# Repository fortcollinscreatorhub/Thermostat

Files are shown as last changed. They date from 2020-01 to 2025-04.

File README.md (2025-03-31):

# What is this repository?

This repository contains files for the custom thermostats used at the Fort
Collins Creator Hub.

# How to clone this repository

This project uses git submodules, unfortunately. To clone the repository, run:

```shell
git clone --recurse-submodules https://github.com/fortcollinscreatorhub/Thermostat
```

If you wish to push back to the github repo, you probably want to clone with
`ssh`, or edit `.git/config` to use ssh URLs after cloning, e.g.:

```shell
git clone --recurse-submodules git@github.com:fortcollinscreatorhub/Thermostat
```

Or after cloning:

```shell
vi .git/config
```

Even if you clone using the ssh URL, you'll still need to edit the remote
definition for each submodule after the initial clone operation.

## Hardware Revisions

v1 was a a breadboard-based design, using some standalone (non-WiFi)
micro-controller; perhaps an AVR or STM32. For this design, we only have the
software and not schematics etc.

v2 uses an ESP32. The PCB design is found in directory [pcb/](pcb/). File
[thermostat.dxf](thermostat.dxf) describes some of the physical design.

## Software Versions

v1 hardware uses the code in directory [code/arduino-v1/](code/arduino-v1/).

v2 hardware can use any of following software stacks:
* A port of the older Arduino code. Found in directory
[code/arduino-esp32/](code/arduino-esp32/).
* WiFi-/MQTT-capable software built using the ESP-IDF framework. Found in
directory [code/esp-idf](code/esp-idf). This version is currently deployed.
* Updated WiFi-/MQTT-capable software built using the ESP-IDF framework, plus
the FCCH "connection manager" component which provides a permanently enabled
password-protected web admin interface. Found in directory
[code/esp-idf-v2](code/esp-idf-v2). This version is not yet deployed.

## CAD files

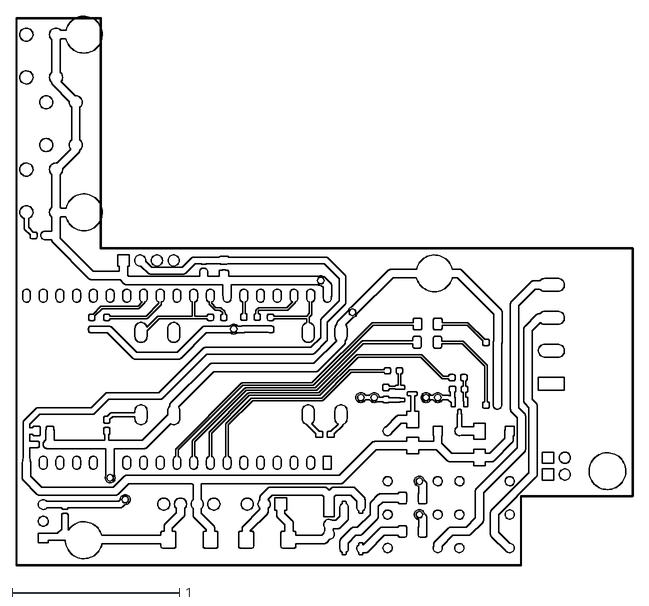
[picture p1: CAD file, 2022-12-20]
pcb/Gerber/Thermostat1-F_Cu.dxf
3.69 x 3.29

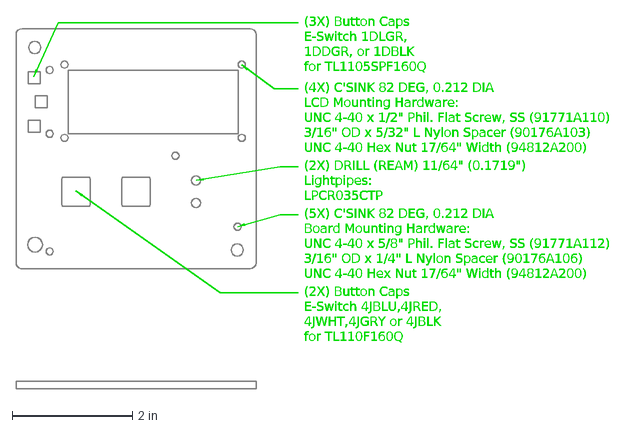
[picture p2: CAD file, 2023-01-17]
thermostat.dxf
(4X) C'SINK 82 DEG, 0.212 DIA LCD Mounting Hardware: UNC 4-40 x 1/2" Phil. Flat Screw, SS (91771A110) 3/16" OD x 5/32" L Nylon Spacer (90176A103) UNC 4-40 Hex N
(3X) Button Caps E-Switch 1DLGR, 1DDGR, or 1DBLK for TL1105SPF160Q
(2X) Button Caps E-Switch 4JBLU,4JRED, 4JWHT,4JGRY or 4JBLK for TL110F160Q
(5X) C'SINK 82 DEG, 0.212 DIA Board Mounting Hardware: UNC 4-40 x 5/8" Phil. Flat Screw, SS (91771A112) 3/16" OD x 1/4" L Nylon Spacer (90176A106) UNC 4-40 Hex 
(2X) DRILL (REAM) 11/64" (0.1719") Lightpipes: LPCR035CTP

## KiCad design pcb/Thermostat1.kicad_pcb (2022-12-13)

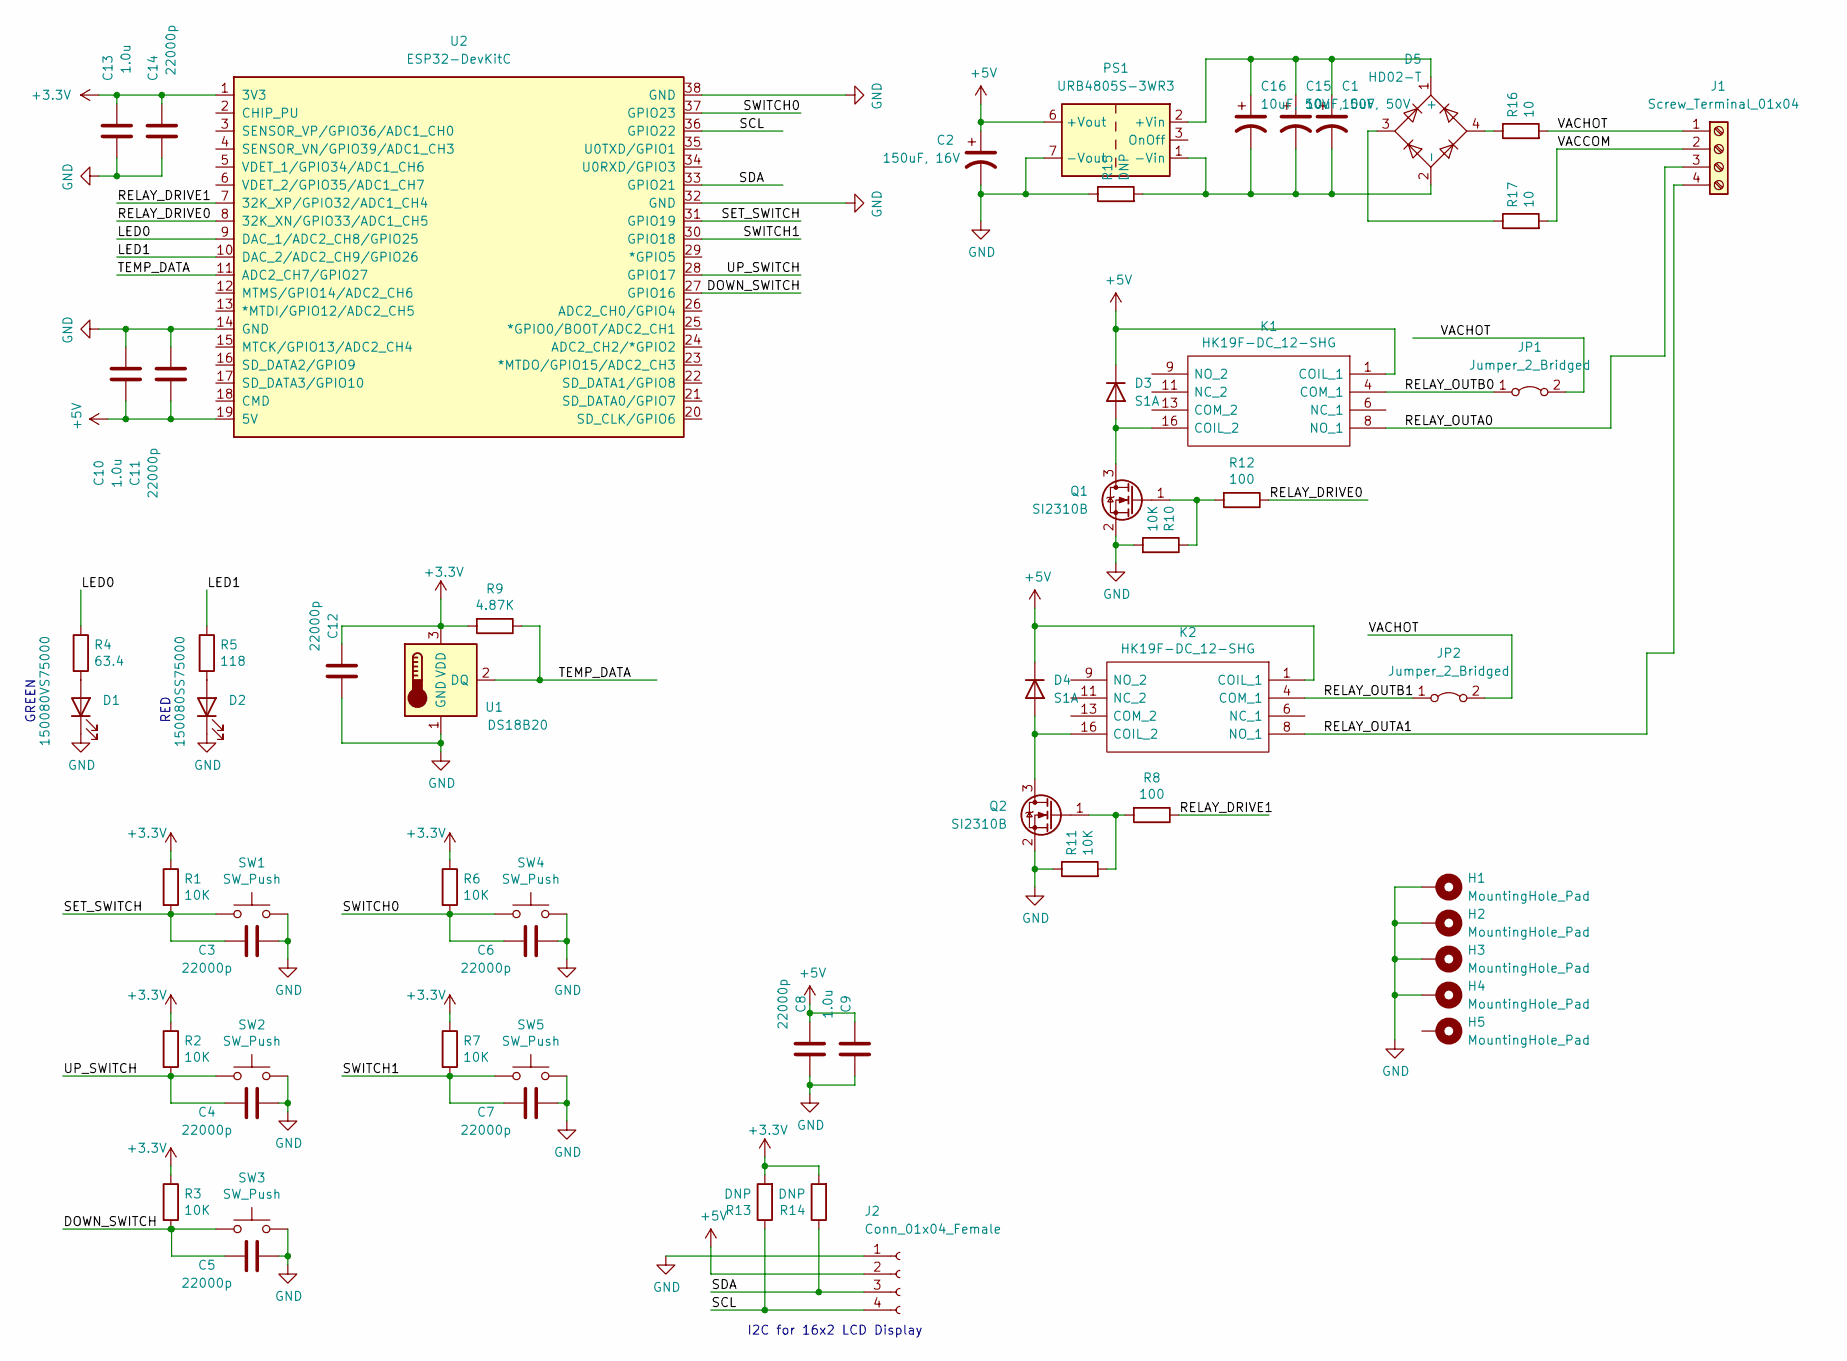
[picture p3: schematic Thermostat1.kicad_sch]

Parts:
C1: 10uF, 50V; CP_EIA-7343-43_Kemet-X_Pad2.25x2.55mm_HandSolder
C2: 150uF, 16V; CP_EIA-7343-43_Kemet-X_Pad2.25x2.55mm_HandSolder
C3, C4, C5, C6, C7, C8, C11, C12, C14: 22000p; C_0603_1608Metric_Pad1.08x0.95mm_HandSolder
C9, C10, C13: 1.0u; C_0805_2012Metric_Pad1.18x1.45mm_HandSolder
C15: 10uF, 50V; CP_Radial_D5.0mm_P2.00mm
C16: 10uF, 50V; CP_Radial_D8.0mm_P5.00mm
D1: 150080VS75000; LED_0603_1608Metric_Pad1.05x0.95mm_HandSolder
D2: 150080SS75000; LED_0603_1608Metric_Pad1.05x0.95mm_HandSolder
D3, D4: S1A; D_SMA
D5: HD02-T; SO-4_4.4x3.9mm_P2.54mm
H1, H2, H3, H4, H5: MountingHole_Pad; MountingHole_3.2mm_M3_DIN965_Pad
J1: Screw_Terminal_01x04; TerminalBlock_Altech_AK300-4_P5.00mm
J2: Conn_01x04_Female; PinHeader_1x04_P2.54mm_Vertical
JP1, JP2: Jumper_2_Bridged; PinHeader_1x02_P2.54mm_Vertical
K1, K2: HK19F-DC_12-SHG; Relay_DPDT_Omron_G5V-2; Manufacturer_Part_Number HK19F-DC 12-SHG
PS1: URB4805S-3WR3; Converter_DCDC_XP_POWER-ITxxxxxS_THT
Q1, Q2: SI2310B; SOT-23
R1, R2, R3, R6, R7, R10, R11: 10K; R_0603_1608Metric_Pad0.98x0.95mm_HandSolder
R4: 63.4; R_1206_3216Metric_Pad1.30x1.75mm_HandSolder
R5: 118; R_1206_3216Metric_Pad1.30x1.75mm_HandSolder
R8, R12: 100; R_0603_1608Metric_Pad0.98x0.95mm_HandSolder
R9: 4.87K; R_0603_1608Metric_Pad0.98x0.95mm_HandSolder
R13, R14: DNP; R_0603_1608Metric_Pad0.98x0.95mm_HandSolder
R15: DNP; R_1206_3216Metric_Pad1.30x1.75mm_HandSolder
R16, R17: 10; R_1206_3216Metric_Pad1.30x1.75mm_HandSolder
SW1, SW2, SW3: SW_Push; SW_PUSH_6mm
SW4, SW5: SW_Push; SW_PUSH-12mm
U1: DS18B20; TO-92_Inline_Wide
U2: ESP32-DevKitC

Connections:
+3.3V: C12.1, C13.1, C14.1, R1.1, R2.1, R3.1, R6.1, R7.1, R9.2, R13.2, R14.2, U1.3 (VDD), U2.1 (3V3)
+5V: C2.1, C8.1, C9.1, C10.2, C11.2, D3.1 (K), D4.1 (K), J2.2, K1.1 (COIL_1), K2.1 (COIL_1), PS1.6 (+Vout), U2.19 (5V)
/DOWN_SWITCH: C5.1, R3.2, SW3.1, U2.27 (GPIO16)
/LED0: R4.1, U2.9 (DAC_1/ADC2_CH8/GPIO25)
/LED1: R5.1, U2.10 (DAC_2/ADC2_CH9/GPIO26)
/RELAY_DRIVE0: R12.1, U2.8 (32K_XN/GPIO33/ADC1_CH5)
/RELAY_DRIVE1: R8.1, U2.7 (32K_XP/GPIO32/ADC1_CH4)
/RELAY_OUTA0: J1.3, K1.8 (NO_1)
/RELAY_OUTA1: J1.4, K2.8 (NO_1)
/RELAY_OUTB0: JP1.1 (A), K1.4 (COM_1)
/RELAY_OUTB1: JP2.1 (A), K2.4 (COM_1)
/SCL: J2.4, R13.1, U2.36 (GPIO22)
/SDA: J2.3, R14.1, U2.33 (GPIO21)
/SET_SWITCH: C3.1, R1.2, SW1.1, U2.31 (GPIO19)
/SWITCH0: C6.1, R6.2, SW4.1, U2.37 (GPIO23)
/SWITCH1: C7.1, R7.2, SW5.1, U2.30 (GPIO18)
/TEMP_DATA: R9.1, U1.2 (DQ), U2.11 (ADC2_CH7/GPIO27)
/UP_SWITCH: C4.1, R2.2, SW2.1, U2.28 (GPIO17)
/VACCOM: J1.2, R17.2
/VACHOT: J1.1, JP1.2 (B), JP2.2 (B), R16.2
GND: C2.2, C3.2, C4.2, C5.2, C6.2, C7.2, C8.2, C9.2, C10.1, C11.1, C12.2, C13.2, C14.2, D1.1 (K), D2.1 (K), H1.1, H2.1, H3.1, H4.1, J2.1, PS1.7 (-Vout), Q1.2 (S), Q2.2 (S), R10.2, R11.1, R15.1, SW1.2, SW2.2, SW3.2, SW4.2, SW5.2, U1.1 (GND), U2.14 (GND), U2.32 (GND), U2.38 (GND)
unnamed: C1.1, C15.1, C16.1, D5.1 (+), PS1.2 (+Vin)
unnamed: C1.2, C15.2, C16.2, D5.2 (-), PS1.1 (-Vin), R15.2
unnamed: D1.2 (A), R4.2
unnamed: D2.2 (A), R5.2
unnamed: D3.2 (A), K1.16 (COIL_2), Q1.3 (D)
unnamed: D4.2 (A), K2.16 (COIL_2), Q2.3 (D)
unnamed: D5.3, R17.1
unnamed: D5.4, R16.1
unnamed: Q1.1 (G), R10.1, R12.2
unnamed: Q2.1 (G), R8.2, R11.2

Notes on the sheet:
I2C for 16x2 LCD Display
RED
GREEN

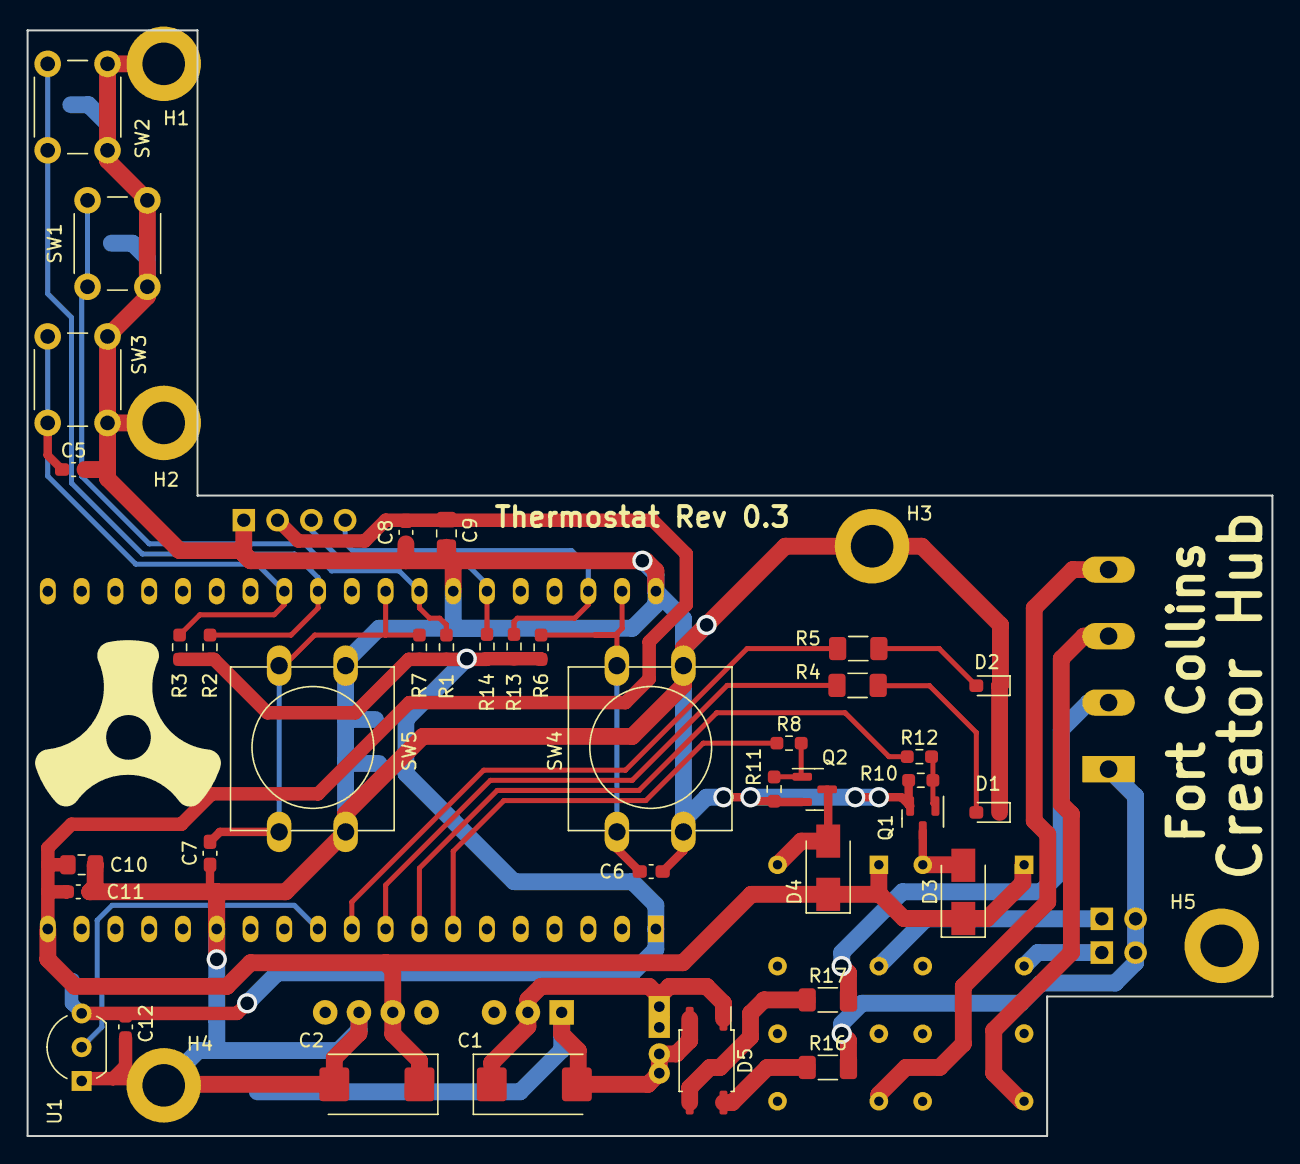
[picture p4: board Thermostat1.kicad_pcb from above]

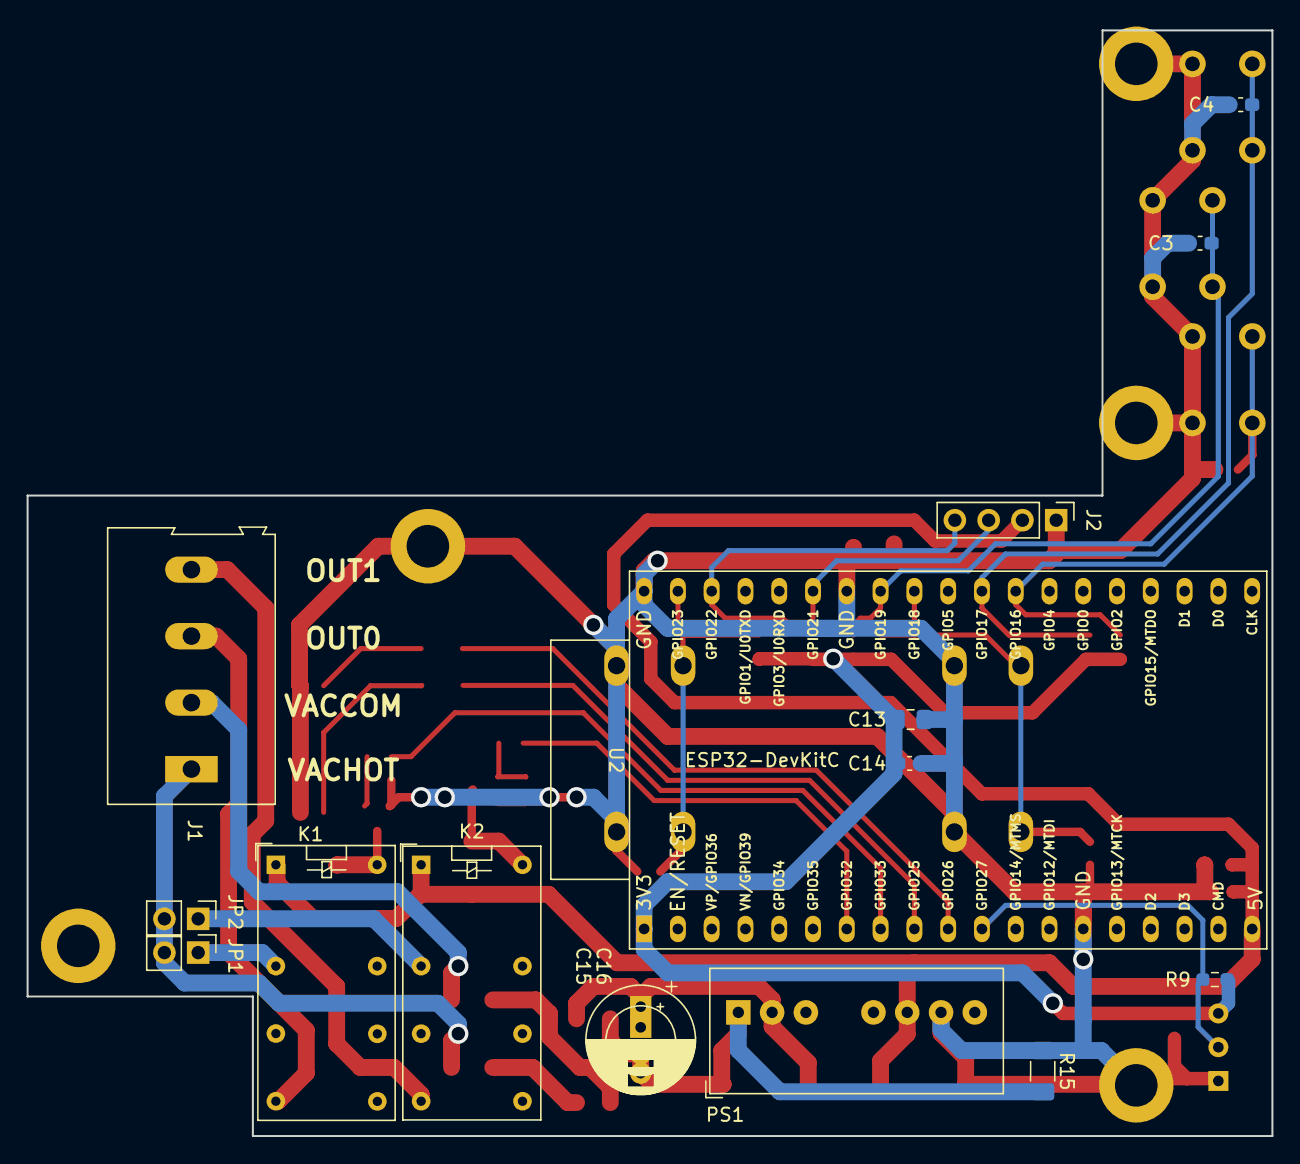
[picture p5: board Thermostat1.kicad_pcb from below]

Board: 2 copper layers, 93.6 x 83.1 mm, 59 parts (16 on the bottom side), 31 nets.

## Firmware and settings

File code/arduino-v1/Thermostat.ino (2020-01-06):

#include <Wire.h>
#include <LCD.h>
#include <LiquidCrystal_I2C.h>
#include <OneWire.h>
#include <DallasTemperature.h>
#include <EEPROM.h>

#define LOOP_DELAY 10           // 10 milliseconds
#define FRAME_LIMIT 200         // 2 seconds
#define SHORT_DEBOUNCE 50L      // 50 milliseconds
#define MEDIUM_DEBOUNCE 200L    // 1/5 second
#define LONG_DEBOUNCE 2000L     // 2 seconds
#define SET_MODE_TIMEOUT 30000L

#define MAX_SETBACK_TEMP 65
#define MIN_SETBACK_TEMP 45
#define MAX_OVERRIDE_TEMP 74
#define MIN_OVERRIDE_TEMP 45
#define MAX_OVERRIDE_TIME 240
#define MIN_OVERRIDE_TIME 5
#define MAX_ANTICIPATION 5.0
#define MIN_ANTICIPATION 0.0
#define MAX_CYCLES_PER_HOUR 10
#define MIN_CYCLES_PER_HOUR 0 // Off

//////////////////////////////////////////////////////////////////////////////////////////
// No user-servicable parts below
//
#define FRAME_HALF_LIMIT (FRAME_LIMIT/2)

#define TEMP_PIN 2
#define RELAY_PIN 4
#define HEATING_LED_PIN 5
#define OVERRIDE_LED_PIN 6

#define SW_SET_PIN 8
#define SW_UP_PIN 9
#define SW_DOWN_PIN 10
#define SW_START_PIN 11
#define SW_CANCEL_PIN 12

#define SETBACK_TEMP_ADDR     0x0
#define OVERRIDE_TEMP_ADDR    (SETBACK_TEMP_ADDR     + sizeof(int))
#define OVERRIDE_MINUTES_ADDR (OVERRIDE_TEMP_ADDR    + sizeof(int))
#define CYCLE_LIMIT_ADDR      (OVERRIDE_MINUTES_ADDR + sizeof(int))
#define CYCLES_PER_HOUR_ADDR  (CYCLE_LIMIT_ADDR      + sizeof(bool))
#define ANTICIPATION_ADDR     (CYCLES_PER_HOUR_ADDR  + sizeof(int))

class Switch {
  private:
    int Pin;
    bool LastVal;
    bool CurrVal;
    unsigned long TriggerTime;
    bool Triggered;

  public:
    Switch(int pin);
    bool Read(unsigned long debounce);
};

Switch::Switch(int pin) {
  Pin = pin;
  CurrVal = false;
  LastVal = false;
  TriggerTime = 0;
  Triggered = false;
}

bool Switch::Read(unsigned long debounce) {
  bool retval = false;
  CurrVal = (digitalRead (Pin) == LOW); // since pullup => pressed equals low

  if (CurrVal && !LastVal) {
    TriggerTime = millis() + debounce;
  }

  if (CurrVal && LastVal && !Triggered && ((long)( millis() - TriggerTime ) >= 0)) {
    Triggered = true;
    retval = true;
  }

  if (!CurrVal) {
    Triggered = false;
  }

  LastVal = CurrVal;
  return (retval);
}

Switch sw_set(SW_SET_PIN);
Switch sw_up(SW_UP_PIN);
Switch sw_down(SW_DOWN_PIN);
Switch sw_start(SW_START_PIN);
Switch sw_cancel(SW_CANCEL_PIN);

LiquidCrystal_I2C  lcd(0x27, 2, 1, 0, 4, 5, 6, 7); // 0x27 is the I2C bus address for an unmodified backpack
OneWire oneWire(TEMP_PIN);
DallasTemperature sensors(&oneWire);

float curr_temp = 0.0;                   // current temperature
int curr_set_point = 55;                 // setpoint temperature based on override or not
unsigned long override_start_time = 0;   // time (in millis) since override button was pressed
unsigned long override_finish_time = 0;  // time (in millis) when override will finish
bool heating = false;                    // are we currently heating?
unsigned long last_cycle_time = 0;       // time (in millis) since last heat cycle started
int frame = 0 ;                          // current display frame
unsigned long timeout_time = 0;          // time any of set/up/down was pressed + timeout period

// the following are restored from EEPROM at powerup
int setback_temp;     // setback or default temperature
int override_temp;    // override temperature
int override_minutes; // number of minutes an override will last
bool cycle_limit;     // enable cycles per hour limit
int cycles_per_hour;  // max number of cycles per hour
float anticipation;   // hysteresis degrees



enum TempMode {
  Setback,
  Override
} temp_mode;

enum SetMode {
  Run,
  SetSetbackTemp,
  SetOverrideTemp,
  SetOverrideTime,
  SetAnticipation,
  SetCyclesPerHour
} set_mode;


void setup()
{
  // set up inputs and output
  pinMode(RELAY_PIN, OUTPUT);
  pinMode(HEATING_LED_PIN, OUTPUT);
  pinMode(OVERRIDE_LED_PIN, OUTPUT);
  digitalWrite(RELAY_PIN, LOW);
  digitalWrite(HEATING_LED_PIN, HIGH);
  digitalWrite(OVERRIDE_LED_PIN, HIGH);

  pinMode(SW_SET_PIN, INPUT_PULLUP);
  pinMode(SW_UP_PIN, INPUT_PULLUP);
  pinMode(SW_DOWN_PIN, INPUT_PULLUP);
  pinMode(SW_START_PIN, INPUT_PULLUP);
  pinMode(SW_CANCEL_PIN, INPUT_PULLUP);

  // activate LCD module
  lcd.begin (16, 2); // for 16 x 2 LCD module
  lcd.setBacklightPin(3, POSITIVE);
  lcd.setBacklight(HIGH);
  lcd.home(); // set cursor to 0,0
  lcd.print("Hello!");

  // initialize temp sensor
  sensors.begin();

  // initialize variables
  temp_mode = Setback;
  set_mode = Run;

  EEPROM.get(SETBACK_TEMP_ADDR, setback_temp);
  EEPROM.get(OVERRIDE_TEMP_ADDR, override_temp);
  EEPROM.get(OVERRIDE_MINUTES_ADDR, override_minutes);
  EEPROM.get(CYCLE_LIMIT_ADDR, cycle_limit);
  EEPROM.get(CYCLES_PER_HOUR_ADDR, cycles_per_hour);
  EEPROM.get(ANTICIPATION_ADDR, anticipation);

  bool upflag = false;
  if (setback_temp < MIN_SETBACK_TEMP) {
    setback_temp = MIN_SETBACK_TEMP;
    upflag = true;
  }
  if (setback_temp > MAX_SETBACK_TEMP) {
    setback_temp = MAX_SETBACK_TEMP;
    upflag = true;
  }
  
  if (override_temp < MIN_OVERRIDE_TEMP) {
    override_temp = MIN_OVERRIDE_TEMP;
    upflag = true;
  }
  if (override_temp > MAX_OVERRIDE_TEMP) {
    override_temp = MAX_OVERRIDE_TEMP;
    upflag = true;
  }
  
  if (override_minutes < MIN_OVERRIDE_TIME) {
    override_minutes = MIN_OVERRIDE_TIME;
    upflag = true;
  }
  if (override_minutes > MAX_OVERRIDE_TIME) {
    override_minutes = MAX_OVERRIDE_TIME;
    upflag = true;
  }

  if (cycles_per_hour < MIN_CYCLES_PER_HOUR) {
    cycles_per_hour = MIN_CYCLES_PER_HOUR;
    cycle_limit = (cycles_per_hour != MIN_CYCLES_PER_HOUR);
    upflag = true;
  }
  if (cycles_per_hour > MAX_CYCLES_PER_HOUR) {
    cycles_per_hour = MAX_CYCLES_PER_HOUR;
    cycle_limit = (cycles_per_hour != MIN_CYCLES_PER_HOUR);
    upflag = true;
  }
  
  if (anticipation < MIN_ANTICIPATION) {
    anticipation = MIN_ANTICIPATION;
    upflag = true;
  } else if (anticipation > MAX_ANTICIPATION) {
    anticipation = MAX_ANTICIPATION;
    upflag = true;
  } else {
    anticipation = MAX_ANTICIPATION;
    upflag = true;
  }
  if (upflag) {
    UpdateEEPROM();
  }
}

void loop()
{
  ModeControl ();
  TempControl ();
  Display ();

  delay(LOOP_DELAY);
}

void ModeControl() {

  // Handle Override and Cancel
  //
  if (sw_start.Read(MEDIUM_DEBOUNCE)) {
    temp_mode = Override;
    override_start_time = millis();
  }
  if (sw_cancel.Read(MEDIUM_DEBOUNCE)) {
    temp_mode = Setback;
  }

  // Handle Set/Up/Down
  //
  bool set_pressed = sw_set.Read((set_mode == Run) ? LONG_DEBOUNCE : SHORT_DEBOUNCE);
  bool up_pressed = sw_up.Read(SHORT_DEBOUNCE);
  bool down_pressed = sw_down.Read(SHORT_DEBOUNCE);

  if (set_pressed || up_pressed || down_pressed) {
    timeout_time = millis() + SET_MODE_TIMEOUT;
  }

  switch (set_mode) {
    case Run:
      if (set_pressed) {
        set_mode = SetSetbackTemp;
      }
      break;

    case SetSetbackTemp:
      if (set_pressed) set_mode = SetOverrideTemp;
      if (up_pressed) {
        if (setback_temp < MAX_SETBACK_TEMP) {
          setback_temp += 1;
        }
      }
      if (down_pressed) {
        if (setback_temp > MIN_SETBACK_TEMP) {
          setback_temp -= 1;
        }
      }
      break;

    case SetOverrideTemp:
      if (set_pressed) set_mode = SetOverrideTime;
      if (up_pressed) {
        if (override_temp < MAX_OVERRIDE_TEMP) {
          override_temp += 1;
        }
      }
      if (down_pressed) {
        if (override_temp > MIN_OVERRIDE_TEMP) {
          override_temp -= 1;
        }
      }
      break;

    case SetOverrideTime:
      if (set_pressed) set_mode = SetAnticipation;
      if (up_pressed) {
        if (override_minutes < MAX_OVERRIDE_TIME) {
          override_minutes += 5;
        } else {
          override_minutes = MIN_OVERRIDE_TIME;
        }
      }
      if (down_pressed) {
        if (override_minutes > MIN_OVERRIDE_TIME) {
          override_minutes -= 5;
          if (override_minutes < 0) override_minutes = MIN_OVERRIDE_TIME;
        } else {
          override_minutes = MAX_OVERRIDE_TIME;
        }
      }
      break;

    case SetAnticipation:
      if (set_pressed) set_mode = SetCyclesPerHour;
      if (up_pressed) {
        if (anticipation < MAX_ANTICIPATION) {
          anticipation += 0.5;
        }
      }
      if (down_pressed) {
        if (anticipation > MIN_ANTICIPATION) {
          anticipation -= 0.5;
          if (anticipation < 0) anticipation = 0;
        }
      }
      break;

    case SetCyclesPerHour:
      if (set_pressed) {
        set_mode = Run;
        UpdateEEPROM();
      }
      if (up_pressed) {
        if (cycles_per_hour < MAX_CYCLES_PER_HOUR) {
          cycles_per_hour += 1;
        } else {
          cycles_per_hour = MIN_CYCLES_PER_HOUR; // wraps
        }
      }
      if (down_pressed) {
        if (cycles_per_hour > MIN_CYCLES_PER_HOUR) {
          cycles_per_hour -= 1;
        } else {
          cycles_per_hour = MAX_CYCLES_PER_HOUR; // wraps
        }
      }
      cycle_limit = (cycles_per_hour != MIN_CYCLES_PER_HOUR);
      break;

    default:
      break;
  }

  // Leave set mode if no buttons are pressed for a period of time
  //
  if ((set_mode != Run) && (((long) (millis() - timeout_time) >= 0))) {
    set_mode = Run;
    UpdateEEPROM();
  }

}

void UpdateEEPROM() {
  int old_setback_temp;
  int old_override_temp;
  int old_override_minutes;
  bool old_cycle_limit;
  int old_cycles_per_hour;
  float old_anticipation;

  EEPROM.get(SETBACK_TEMP_ADDR, old_setback_temp);
  EEPROM.get(OVERRIDE_TEMP_ADDR, old_override_temp);
  EEPROM.get(OVERRIDE_MINUTES_ADDR, old_override_minutes);
  EEPROM.get(CYCLE_LIMIT_ADDR, old_cycle_limit);
  EEPROM.get(CYCLES_PER_HOUR_ADDR, old_cycles_per_hour);
  EEPROM.get(ANTICIPATION_ADDR, old_anticipation);
  
  if (setback_temp != old_setback_temp)         EEPROM.put(SETBACK_TEMP_ADDR, setback_temp);
  if (override_temp != old_override_temp)       EEPROM.put(OVERRIDE_TEMP_ADDR, override_temp);
  if (override_minutes != old_override_minutes) EEPROM.put(OVERRIDE_MINUTES_ADDR, override_minutes);
  if (cycle_limit != old_cycle_limit)           EEPROM.put(CYCLE_LIMIT_ADDR, cycle_limit);
  if (cycles_per_hour != old_cycles_per_hour)   EEPROM.put(CYCLES_PER_HOUR_ADDR, cycles_per_hour);
  if (anticipation != old_anticipation)         EEPROM.put(ANTICIPATION_ADDR, anticipation);
}

// This is the heart of the thermostat: the control loop
// It reads the temperature and engages or disengages the relay as needed
void TempControl() {
  // read the temperature every 100th frame if we are not in set mode - o.w. there can be delays between
  // pressing a button and it taking effect
  //
  if ((set_mode == Run) && ((frame % 100) == 0)) {
    sensors.requestTemperatures(); // Send the command to get temperatures
    curr_temp = sensors.getTempFByIndex(0);
  }

  // see if the override has timed out
  //
  override_finish_time = override_start_time + (60000UL * (unsigned long) override_minutes);
  if ((temp_mode == Override) && (((long) (millis() - override_finish_time) >= 0))) {
    temp_mode = Setback;
  }

  // calculate set point and whether it's OK to start a new cycle based on cycles_per_hour
  //
  curr_set_point = (temp_mode == Override) ? override_temp : setback_temp;

  unsigned long next_cycle_time = cycle_limit ? (last_cycle_time + (3600000UL / (unsigned long) cycles_per_hour)) : last_cycle_time;

  if (!heating
      && (curr_temp < (((float) curr_set_point) - anticipation))
      && (!cycle_limit || (((long)( millis() - next_cycle_time ) >= 0)))) {
    heating = true;
    last_cycle_time = millis();
  }

  if (heating && (curr_temp >= (float) curr_set_point)) {
    heating = false;
  }

  if (heating) {
    digitalWrite(RELAY_PIN, HIGH);
  } else {
    digitalWrite(RELAY_PIN, LOW);
  }
}


void Display() {

  // set status LEDs
  digitalWrite(HEATING_LED_PIN, heating);
  digitalWrite(OVERRIDE_LED_PIN, (temp_mode == Override));

  // write to LCD matrix display
  lcd.home (); // set cursor to 0,0

  switch (set_mode) {

    // RUN
    case Run:
      lcd.print("Temp:      ");
      lcd.print(curr_temp, 0);
      lcd.print("F  ");

      lcd.setCursor (0, 1);       // go to start of 2nd line

      if ((temp_mode == Setback) || (frame < FRAME_HALF_LIMIT)) {
        lcd.print("Set Point: ");
        lcd.print(curr_set_point);
        lcd.print("F  ");
      }
      if ((temp_mode == Override) && (frame >= FRAME_HALF_LIMIT)) {
        lcd.print("Ovrd Time: ");
        long time_left = (override_finish_time - millis());
        print_minutes ((int) (time_left / 60000L) + 1);
      }
      break;

    // Setback Temp
    case SetSetbackTemp:
      lcd.print("Setback Temp:   ");
      lcd.setCursor (0, 1); 
      lcd.print(setback_temp);
      lcd.print("              ");
      break;

    // Override Temp
    case SetOverrideTemp:
      lcd.print("Override Temp:  ");
      lcd.setCursor (0, 1);
      lcd.print(override_temp);
      lcd.print("              ");
      break;

    // Override Time
    case SetOverrideTime:
      lcd.print("Override Time:  ");
      lcd.setCursor (0, 1);
      print_minutes(override_minutes);
      lcd.print("            ");
      break;

    // Anticipation
    case SetAnticipation:
      lcd.print("Anticipation:   ");
      lcd.setCursor (0, 1);
      lcd.print(anticipation,1);
      lcd.print("             ");
      break;

    // Cycles/Hour
    case SetCyclesPerHour:
      lcd.print("Cycles/Hour:    ");
      lcd.setCursor (0, 1);
      if (cycle_limit) {
        lcd.print(cycles_per_hour);
        lcd.print("              ");
      } else {
        lcd.print("-               ");
      }
      break;

    default:
      break;

  }

  //lcd.setBacklight(LOW);      // Backlight off
  //delay(250);
  //lcd.setBacklight(HIGH);     // Backlight on
  //delay(1000);
  frame += 1;
  frame = frame % FRAME_LIMIT;
}

void print_minutes(int t) {
  int hours = t / 60;
  int minutes = t % 60;
  if (hours > 0) {
    lcd.print(hours);
  } else {
    lcd.print(" ");
  }
  lcd.print(":");
  if (minutes < 10) {
    lcd.print("0");
  }
  lcd.print(minutes);
  lcd.print(" ");
}

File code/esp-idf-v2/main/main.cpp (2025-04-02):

// Copyright 2025 Stephen Warren <swarren@wwwdotorg.org>
// SPDX-License-Identifier: MIT

#include <driver/gpio.h>
#include <esp_log.h>
#include <freertos/FreeRTOS.h>
#include <freertos/task.h>

#include <fcch_connmgr/cm.h>
#include <fcch_connmgr/cm_conf.h>
#include <fcch_connmgr/cm_mqtt.h>
#include <fcch_connmgr/cm_util.h>

#include "buttons.h"
#include "lcd.h"
#include "mqtt.h"
#include "thermometer.h"

#define BLOCK_TIME (10 / portTICK_PERIOD_MS)
#define TICKS_PER_TEMP_REQUEST 5

#define MAIN_GPIO_RELAY GPIO_NUM_33
#define MAIN_GPIO_HEATING_LED GPIO_NUM_26
#define MAIN_GPIO_OVERRIDE_LED GPIO_NUM_25

enum main_message_id {
    MAIN_MESSAGE_TIMER,
    MAIN_MESSAGE_BUTTON,
    MAIN_MESSAGE_TEMP_F,
    MAIN_MESSAGE_EVALUATE_HEATING
};

struct main_message {
    main_message_id id;
    union {
        buttons_id button_id;
        float temp_f;
        // For messages without any parameter:
        uint32_t none;
    };
};

static const char *TAG = "main";
static QueueHandle_t main_queue;
static TimerHandle_t main_1s_timer;
static uint32_t main_thermostat_errors;
static uint32_t main_ticks_since_temp_request = TICKS_PER_TEMP_REQUEST;
static bool main_force_heat;
static uint16_t main_override_time_left;
static uint16_t main_mqtt_time_left;
static bool main_heating_on;
// For LCD & MQTT reporting:
static float main_last_temp_f;
static float main_target_temp_f;

static void main_item_val_default_f_1(cm_conf_item * /*item*/, cm_conf_p_val p_val_u) {
    *p_val_u.f = 1;
}

static void main_item_val_default_f_3(cm_conf_item * /*item*/, cm_conf_p_val p_val_u) {
    *p_val_u.f = 3;
}

static void main_item_val_default_f_50(cm_conf_item * /*item*/, cm_conf_p_val p_val_u) {
    *p_val_u.f = 50;
}

static void main_item_val_default_f_70(cm_conf_item * /*item*/, cm_conf_p_val p_val_u) {
    *p_val_u.f = 70;
}

static void main_item_val_default_u16_2h_in_s(cm_conf_item * /*item*/, cm_conf_p_val p_val_u) {
    *p_val_u.u16 = 2 * 60 * 60;
}

static float main_item_val_sensor_offset;
static cm_conf_item main_item_sensor_offset = {
    .slug_name = "so", // Sensor Offset
    .text_name = "Sensor Offset",
    .type = CM_CONF_ITEM_TYPE_FLOAT,
    .p_val = {.f = &main_item_val_sensor_offset },
    .default_func = &cm_conf_default_f_0,
};

static float main_item_val_fallback_target_temp_f;
static cm_conf_item main_item_fallback_target_temp_f = {
    .slug_name = "ftt", // Fallback Target Temp
    .text_name = "Fallback Target Temperature",
    .type = CM_CONF_ITEM_TYPE_FLOAT,
    .p_val = {.f = &main_item_val_fallback_target_temp_f },
    .default_func = &main_item_val_default_f_50,
};

static float main_item_val_fallback_hysteresis_low;
static cm_conf_item main_item_fallback_hysteresis_low = {
    .slug_name = "fhl", // Fallback Hysteresis Low
    .text_name = "Fallback Hysteresis Offset Low",
    .type = CM_CONF_ITEM_TYPE_FLOAT,
    .p_val = {.f = &main_item_val_fallback_hysteresis_low },
    .default_func = &main_item_val_default_f_3,
};

static float main_item_val_fallback_hysteresis_high;
static cm_conf_item main_item_fallback_hysteresis_high = {
    .slug_name = "fhh", // Fallback Hysteresis Offset High
    .text_name = "Fallback Hysteresis High",
    .type = CM_CONF_ITEM_TYPE_FLOAT,
    .p_val = {.f = &main_item_val_fallback_hysteresis_high },
    .default_func = &main_item_val_default_f_1,
};

static uint16_t main_item_val_override_duration;
static cm_conf_item main_item_override_duration = {
    .slug_name = "od", // Override Duration
    .text_name = "Override Duration (seconds)",
    .type = CM_CONF_ITEM_TYPE_U16,
    .p_val = {.u16 = &main_item_val_override_duration },
    .default_func = &main_item_val_default_u16_2h_in_s,
};

static float main_item_val_override_target_temp_f;
static cm_conf_item main_item_override_target_temp_f = {
    .slug_name = "ott", // Override Target Temp
    .text_name = "Override Target Temperature",
    .type = CM_CONF_ITEM_TYPE_FLOAT,
    .p_val = {.f = &main_item_val_override_target_temp_f },
    .default_func = &main_item_val_default_f_70,
};

static float main_item_val_override_hysteresis_low;
static cm_conf_item main_item_override_hysteresis_low = {
    .slug_name = "ohl", // Override Hysteresis Low
    .text_name = "Override Hysteresis Offset Low",
    .type = CM_CONF_ITEM_TYPE_FLOAT,
    .p_val = {.f = &main_item_val_override_hysteresis_low },
    .default_func = &main_item_val_default_f_3,
};

static float main_item_val_override_hysteresis_high;
static cm_conf_item main_item_override_hysteresis_high = {
    .slug_name = "ohh", // Override Hysteresis High
    .text_name = "Override Hysteresis Offset High",
    .type = CM_CONF_ITEM_TYPE_FLOAT,
    .p_val = {.f = &main_item_val_override_hysteresis_high },
    .default_func = &main_item_val_default_f_1,
};

static cm_conf_item *main_items[] = {
    &main_item_sensor_offset,
    &main_item_fallback_target_temp_f,
    &main_item_fallback_hysteresis_low,
    &main_item_fallback_hysteresis_high,
    &main_item_override_duration,
    &main_item_override_target_temp_f,
    &main_item_override_hysteresis_low,
    &main_item_override_hysteresis_high,
};

static cm_conf_page main_conf_page = {
    .slug_name = "ts", // ThermoStat
    .text_name = "Thermostat",
    .items = main_items,
    .items_count = ARRAY_SIZE(main_items),
};

lcd_thermostat_info lcd_get_thermostat_info() {
    return {main_last_temp_f, main_target_temp_f, main_override_time_left, main_force_heat};
}

mqtt_status mqtt_get_status() {
    return {main_last_temp_f, main_target_temp_f, main_heating_on, main_override_time_left, main_force_heat};
}

void buttons_on_click(buttons_id id) {
    main_message msg{
        .id = MAIN_MESSAGE_BUTTON,
        .button_id = id,
    };
    assert(xQueueSend(main_queue, &msg, BLOCK_TIME) == pdTRUE);
}

static void main_http_action_button_start() {
    buttons_on_click(BUTTONS_ID_START);
}

static const char *main_http_action_button_start_description() {
    return "Override Start";
}

static void main_http_action_button_cancel() {
    buttons_on_click(BUTTONS_ID_CANCEL);
}

static const char *main_http_action_button_cancel_description() {
    return "Override Cancel";
}

static void main_http_action_force_heat_toggle() {
    main_force_heat = !main_force_heat;

    main_message msg{
        .id = MAIN_MESSAGE_EVALUATE_HEATING,
        .none = 0,
    };
    assert(xQueueSend(main_queue, &msg, BLOCK_TIME) == pdTRUE);
}

static const char *main_http_action_force_heat_toggle_description() {
    if (main_force_heat) {
        return "Force Heat (Is On)";
    } else {
        return "Force Heat (Is Off)";
    }
}

void thermometer_on_error() {
    main_thermostat_errors++;
    assert(main_thermostat_errors < 10);
}

void thermometer_on_temp_f(float temp_f) {
    main_thermostat_errors = 0;

    main_message msg{
        .id = MAIN_MESSAGE_TEMP_F,
        .temp_f = temp_f,
    };
    assert(xQueueSend(main_queue, &msg, BLOCK_TIME) == pdTRUE);
}
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

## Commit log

2022-11-16 Added KiCad PCB files.
    [Thermostat1-B.Cu.gbl, Thermostat1-B.Mask.gbs, Thermostat1-B.SilkS.gbo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]
2022-11-16 Added dxf sketch of thermostat repackage along with some datasheets for parts to use.
    [thermostat.dxf]
2022-12-10 New revision of pcb with updates suggested by Steve P.
    [Thermostat1-B.Cu.gbl, Thermostat1-B.Mask.gbs, Thermostat1-B.SilkS.gbo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]
2022-12-10 Removed some files which don't appear to be used anymore by newer version of KiCad.
    [Thermostat1.dsn, Thermostat1.sch]
2022-12-11 Fixed a couple issues on schematic and layout - swapped power supplies on external components and pullups from 5V to 3.3V, moved input connector so it's further from the edge of the box, increased sp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
    [Thermostat1.kicad_pcb, Thermostat1.kicad_sch]
2022-12-13 A few more fixes for Rev 0.3 - more options for power input caps as well as some sense resistors, also remade gerber files.
    [Thermostat1-B_Cu.gbl, Thermostat1-B_Mask.gbs, Thermostat1-B_Silkscreen.gbo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]
2022-12-20 Imported new pcb layout into mechanical DXF, added 'vent' hole for thermometer part.
    [Thermostat1-F_Cu.dxf, thermostat.dxf]
2023-01-17 Added callouts for lightpipes and button key caps.
    [thermostat.dxf]
2023-01-24 Adding ESP32 versions
    Adding ESP32 versions
2023-02-06 Update main.c
    Updated temperature read
2025-03-26 esp-idf-v2: components: add esp32-smbus
    git clone https://github.com/DavidAntliff/esp32-smbus.git
    (This yielded commit 1bca026c4fe8d28f9cb76da30da05e8a70a8231f)
    rm -rf esp32-smbus/.git/
    git add esp32-smbus
2025-03-26 esp-idf-v2: components: esp32-smbus: port to ESP-IDF v5.4
2025-03-26 esp-idf-v2: components: add esp32-i2c-lcd1602
    git clone https://github.com/DavidAntliff/esp32-i2c-lcd1602.git
    (This yielded commit c9026dd74f63e64943321a4dea5f4ce9f8d9e9c5)
    rm -rf esp32-i2c-lcd1602/.git/
    git add esp32-i2c-lcd1602
2025-03-26 esp-idf-v2: components: esp32-i2c-lcd1602: port to ESP-IDF v5.4
2025-03-28 esp-idf-v2: quantize temps in MQTT msgs
    Format temperatures to 1 decimal place in MQTT messages. This matches
    the LCD display, and produces "simpler" values in messages, and Node-RED
    status displays.
2025-04-02 fcch_connmgr: switch to latest version
    This version brings support for CM_CONF_ITEM_TYPE_FLOAT, which the
    thermostat app will use in the next commit.
2025-04-02 Convert config items to floats
    This allows finer-grained control, and support for signed values, which
    is useful for the sensor offset value.
2025-04-02 Add HTTP buttons for start/cancel override
2025-04-02 Add HTTP button to force heating on for testing
2025-05-24 add shim design for probe mounting tube
    Sometimes the right-angle PVC joint doesn't push all the way onto the
    PVC extending from the box. This shim can be placed around the piece
    that extends from the box between the box and the right-angle piece to
    square everything up.
